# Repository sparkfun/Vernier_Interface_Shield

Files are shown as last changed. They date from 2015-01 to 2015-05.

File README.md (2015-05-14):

Vernier Interface Shield
========================

Vernier Interface Shield

[*Vernier Interface Shield (DEV-12858)*](https://www.sparkfun.com/products/12858)

This shield enables Arduino Uno footprint compatible boards to be connected to Vernier sensors. 

Repository Contents
-------------------

* **/Hardware** - Eagle PCB layout files
* **/Libraries** - Arduino library for using the Vernier Shield
* **/Production** - Files to support SparkFun production

Documentation
--------------
* **[Library](https://github.com/sparkfun/SparkFun_Vernier_Interface_Shield_Arduino_Library)** - Arduino library for the Vernier shield. 
* **[Hookup Guide](https://learn.sparkfun.com/tutorials/vernier-shield-hookup-guide)** - Basic hookup guide for the Vernier Shield.
* **[SparkFun Fritzing repo](https://github.com/sparkfun/Fritzing_Parts)** - Fritzing diagrams for SparkFun products.
* **[SparkFun 3D Model repo](https://github.com/sparkfun/3D_Models)** - 3D models of SparkFun products. 

Product Versions
----------------
* [DEV-11897](https://www.sparkfun.com/products/retired/11897)- Hardware version 1.1. Retired. 

Version History
---------------
* [v1.2](https://github.com/sparkfun/Vernier_Interface_Shield/tree/v1.2) -GitHub version 1.2
* [v1.1](https://github.com/sparkfun/Vernier_Interface_Shield/tree/v1.1) -GitHub version 1.1

License Information
-------------------
This product is _**open source**_! 

The **hardware** is released under [Creative Commons ShareAlike 4.0 International](https://creativecommons.org/licenses/by-sa/4.0/).

The **code** is beerware; if you see me (or any other SparkFun employee) at the local, and you've found our code helpful, please buy us a round!

Please use, reuse, and modify these files as you see fit. Please maintain attribution to SparkFun Electronics and release anything derivative under the same license.

Distributed as-is; no warranty is given.

- Your friends at SparkFun.

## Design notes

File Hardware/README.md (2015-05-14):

SparkFun <PRODUCT NAME> Design Files
=====================================

The .sch and .brd files hare are Eagle CAD schematic and PCB design files from SparkFun Electronics.
A freeware version of Eagle can be found [here](http://www.cadsoftusa.com/download-eagle/freeware/). 

License
---------
This product is open source! 
The hardware is released under [Creative Commons ShareAlike 4.0 International](https://creativecommons.org/licenses/by-sa/4.0/).

Please use, reuse, and modify these files as you see fit. Please maintain attribution to SparkFun Electronics and release anything derivative under the same license.

Distributed as-is; no warranty is given.

- Your friends at SparkFun.

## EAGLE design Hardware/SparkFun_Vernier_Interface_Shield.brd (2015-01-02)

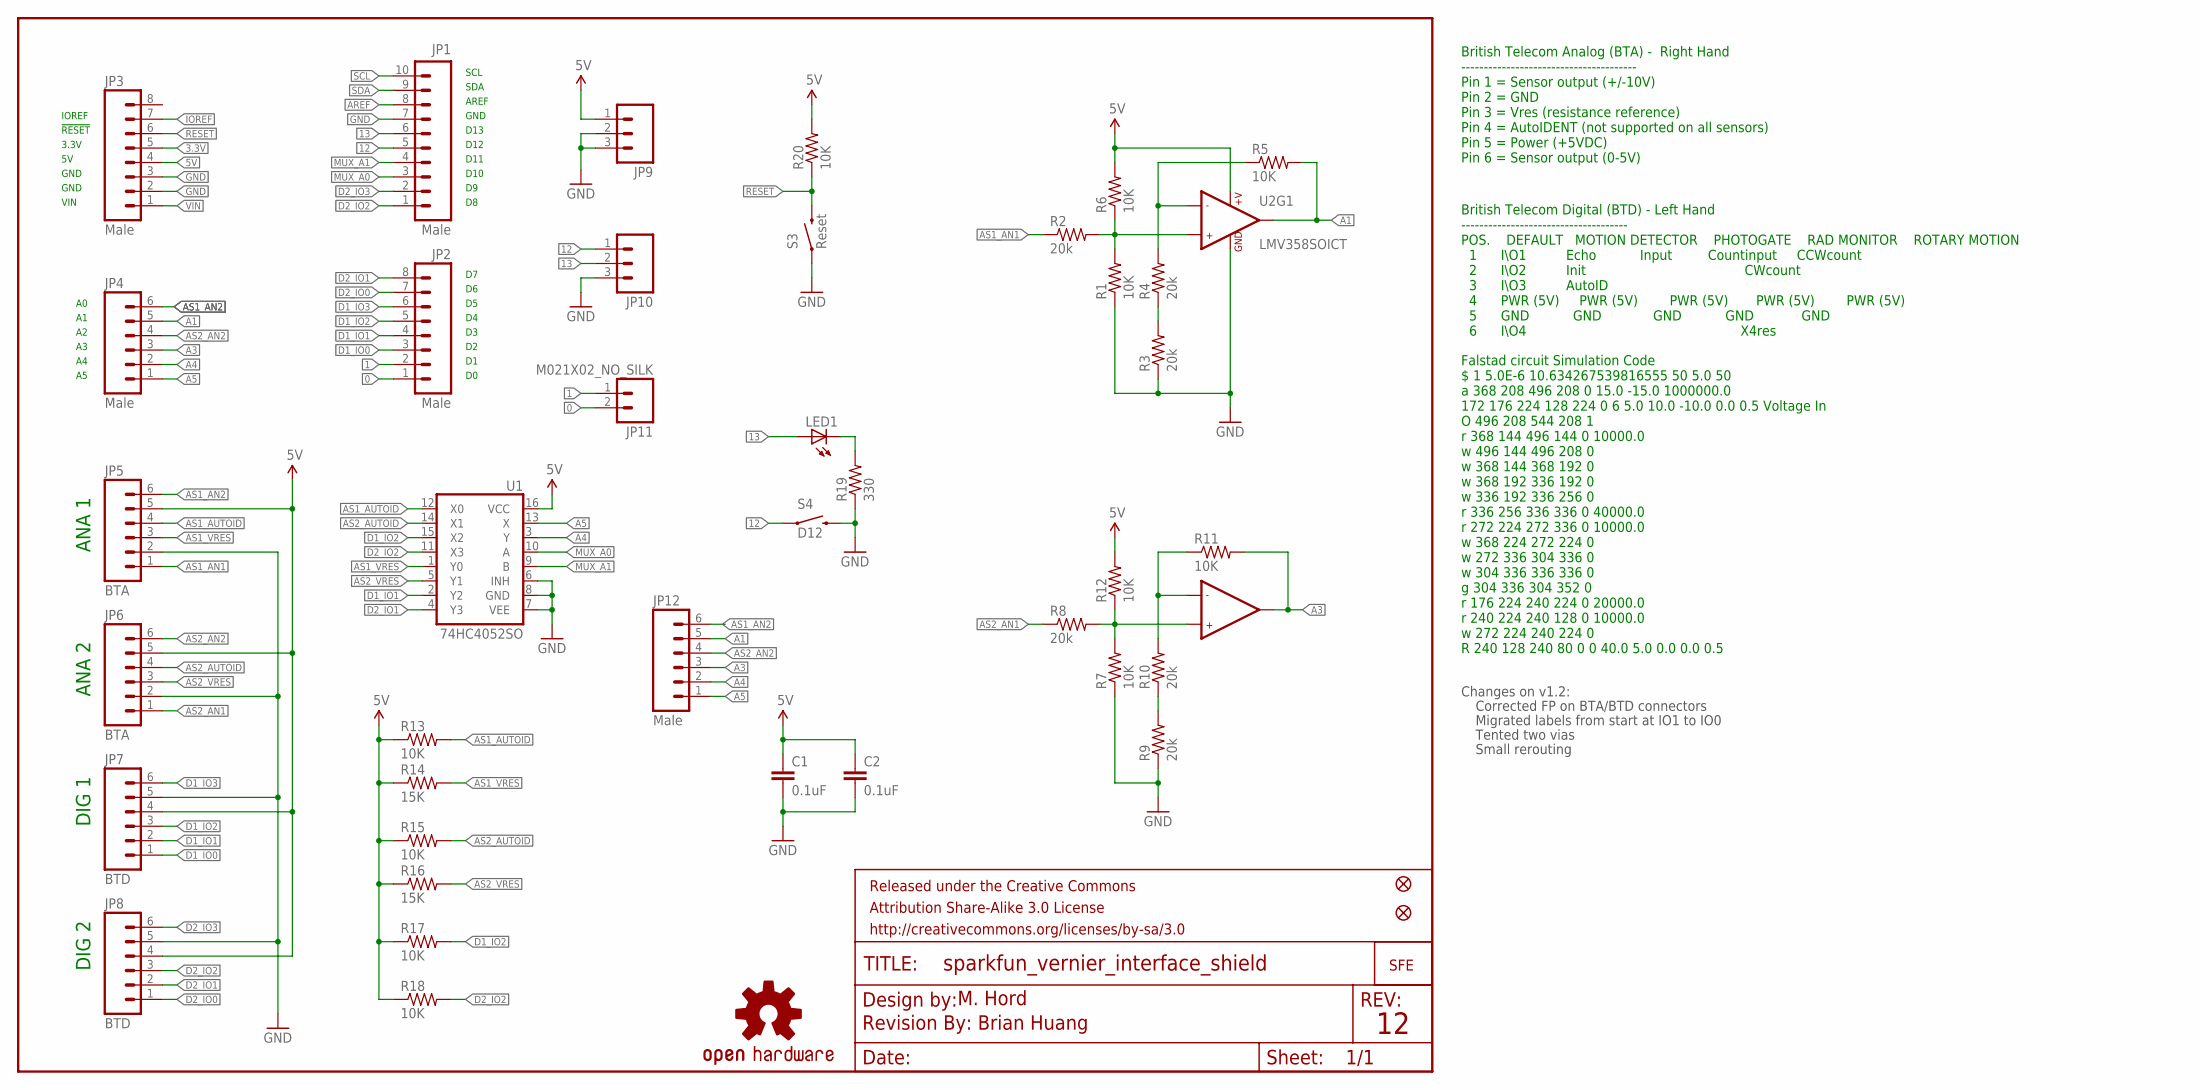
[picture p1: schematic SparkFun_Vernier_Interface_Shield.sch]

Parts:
C1, C2: 0.1uF; 0603-CAP
FID1, FID2: FIDUCIAL1X2; FIDUCIAL-1X2
FRAME1: FRAME-LETTER; CREATIVE_COMMONS
JP1: Male; 1X10_SMD_MALE
JP2, JP3: Male; 1X08_SMD_MALE
JP4: Male; 1X06_SMD_MALE
JP5, JP6: BTA
JP7, JP8: BTD
JP9, JP10: M031X03_NO_SILK; 1X03_NO_SILK
JP11: M021X02_NO_SILK; 1X02_NO_SILK
JP12: Male; 1X06
LED1: LED5MM
LOGO2: OSHW-LOGOS; OSHW-LOGO-S
LOGO_1: LOGO-SFESK; SFE-LOGO-FLAME
R1, R5, R6, R7, R11, R12, R13, R15, R17, R18, R20: 10K; 0603-RES
R2, R3, R4, R8, R9, R10: 20k; 0603-RES
R14, R16: 15K; 0603-RES
R19: 330; 0603-RES
S3: Reset; TACTILE-PTH
S4: D12; TACTILE-PTH
U1: 74HC4052SO; SO16
U2: LMV358SOICT; SO08-TIGHT
U$1: REVISION

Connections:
0: JP2.1, JP11.2
1: JP2.2, JP11.1
3.3V: JP3.5
5V: C1.1, C2.1, JP3.4, JP5.5, JP6.5, JP7.4, JP8.4, JP9.1, R6.2, R12.2, R13.1, R14.1, R15.1, R16.1, R17.1, R18.1, R20.2, U1.16 (VCC), U2.8 (+V)
12: JP1.5, JP10.1, S4.1
13: JP1.6, JP10.2, LED1.A
A1: JP4.5, JP12.5, R5.2, U2.1 (OUT1)
A3: JP4.3, JP12.3, R11.2, U2.7 (OUT2)
A4: JP4.2, JP12.2, U1.3 (Y)
A5: JP4.1, JP12.1, U1.13 (X)
AREF: JP1.8
AS1_AN1: JP5.1, R2.1
AS1_AN2: JP4.6, JP5.6, JP12.6
AS1_AUTOID: JP5.4, R13.2, U1.12 (X0)
AS1_VRES: JP5.3, R14.2, U1.1 (Y0)
AS2_AN1: JP6.1, R8.1
AS2_AN2: JP4.4, JP6.6, JP12.4
AS2_AUTOID: JP6.4, R15.2, U1.14 (X1)
AS2_VRES: JP6.3, R16.2, U1.5 (Y1)
D1_IO0: JP2.3, JP7.1
D1_IO1: JP2.4, JP7.2, U1.2 (Y2)
D1_IO2: JP2.5, JP7.3, R17.2, U1.15 (X2)
D1_IO3: JP2.6, JP7.6
D2_IO0: JP2.7, JP8.1
D2_IO1: JP2.8, JP8.2, U1.4 (Y3)
D2_IO2: JP1.1, JP8.3, R18.2, U1.11 (X3)
D2_IO3: JP1.2, JP8.6
GND: C1.2, C2.2, JP1.7, JP3.2, JP3.3, JP5.2, JP6.2, JP7.5, JP8.5, JP9.2, JP9.3, JP10.3, R1.1, R3.1, R7.1, R9.1, R19.1, S3.1, S4.3 (2), U1.6 (INH), U1.7 (VEE), U1.8 (GND), U2.4 (GND)
IOREF: JP3.7
MUX_A0: JP1.3, U1.10 (A)
MUX_A1: JP1.4, U1.9 (B)
unnamed: R1.2, R2.2, R6.1, U2.3 (+IN1)
unnamed: R3.2, R4.1
unnamed: R4.2, R5.1, U2.2 (-IN1)
unnamed: R9.2, R10.1
unnamed: R7.2, R8.2, R12.1, U2.5 (+IN2)
unnamed: R10.2, R11.1, U2.6 (-IN2)
unnamed: LED1.K (C), R19.2
RESET: JP3.6, R20.1, S3.3 (2)
SCL: JP1.10
SDA: JP1.9
VIN: JP3.1

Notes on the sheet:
SCL
SDA
AREF
GND
D13
D12
D11
D10
VIN
3.3V
!RESET
IOREF
ANA 1
ANA 2
DIG 1
DIG 2
M. Hord
British Telecom Analog (BTA) - Right Hand --------------------------------------- Pin 1 = Sensor output (+/-10V) Pin 2 = GND Pin 3 = Vres (resistance reference) Pin 4 = AutoIDENT (not supported on all sensors) Pin 5 = Power (+5VDC) Pin 6 = Sensor output (0-5V)
British Telecom Digital (BTD) - Left Hand ------------------------------------- POS. DEFAULT MOTION DETECTOR PHOTOGATE RAD MONITOR ROTARY MOTION 1 I\\O1 Echo Input Countinput CCWcount 2 I\\O2 Init CWcount 3 I\\O3 AutoID 4 PWR (5V) PWR (5V) PWR (5V) PWR (5V) PWR (5V) 5 GND GND GND GND GND 6 I\\O4 X4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
Falstad circuit Simulation Code $ 1 5.0E-6 10.634267539816555 50 5.0 50 a 368 208 496 208 0 15.0 -15.0 1000000.0 172 176 224 128 224 0 6 5.0 10.0 -10.0 0.0 0.5 Voltage In O 496 208 544 208 1 r 368 144 496 144 0 10000.0 w 496 144 496 208 0 w 368 144 368 192 0 w 368 192 336 192 0 w 336 192 336 256 0 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
Changes on v1.2:
Corrected FP on BTA/BTD connectors
Migrated labels from start at IO1 to IO0
Tented two vias
Small rerouting
Brian Huang

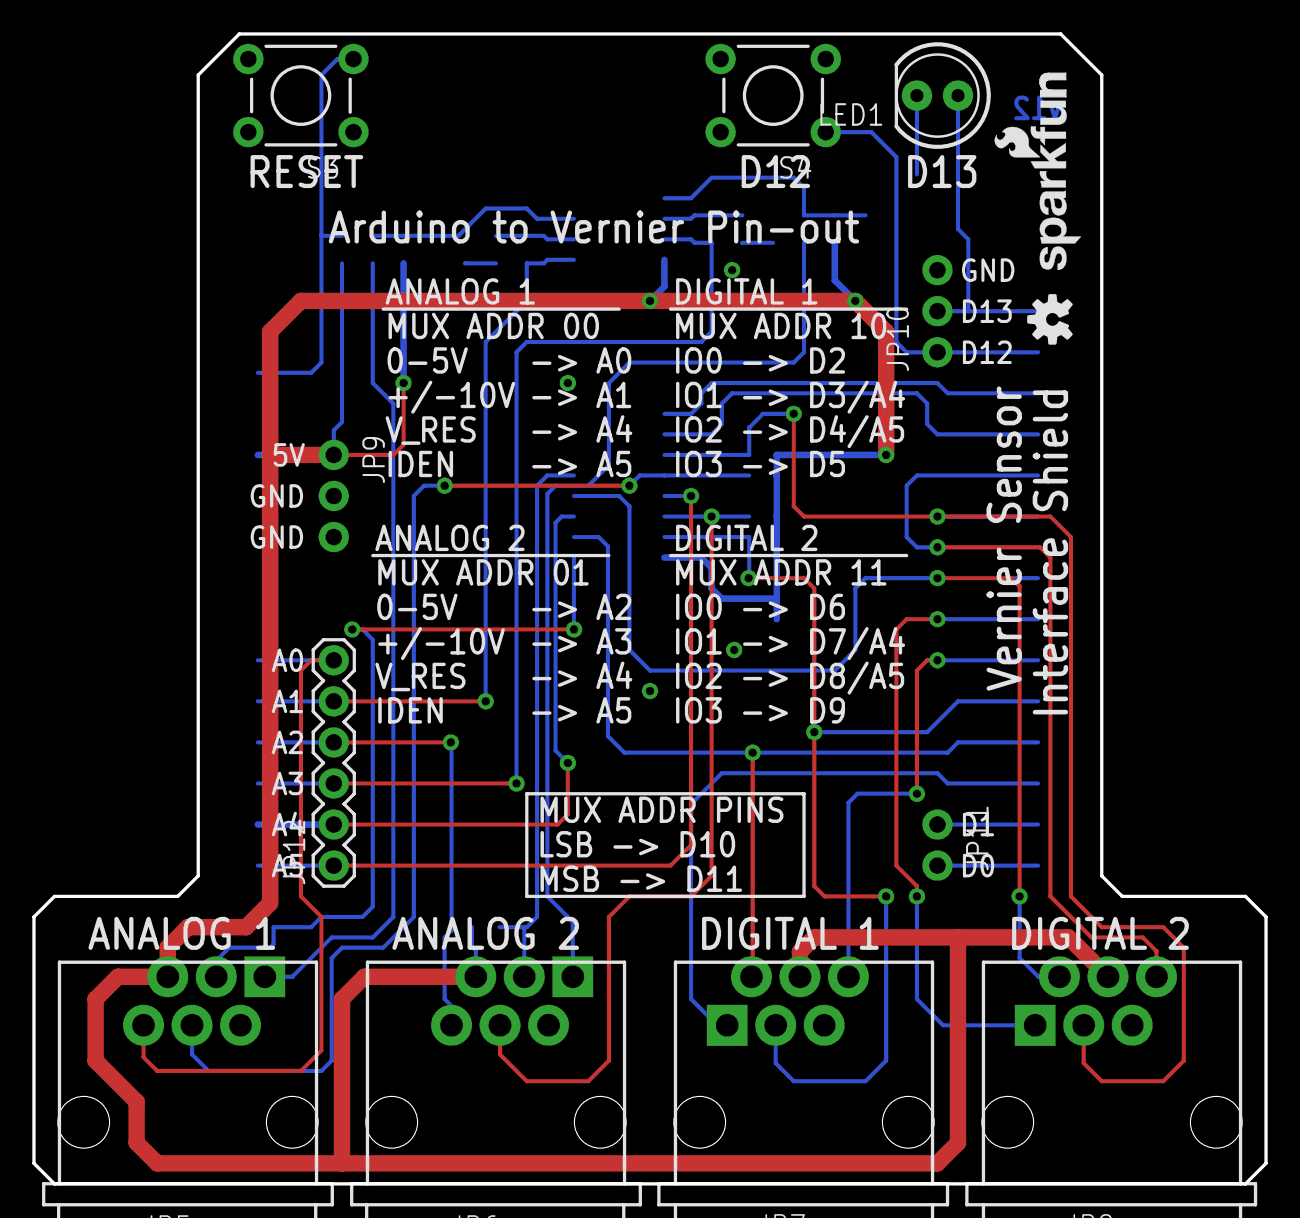
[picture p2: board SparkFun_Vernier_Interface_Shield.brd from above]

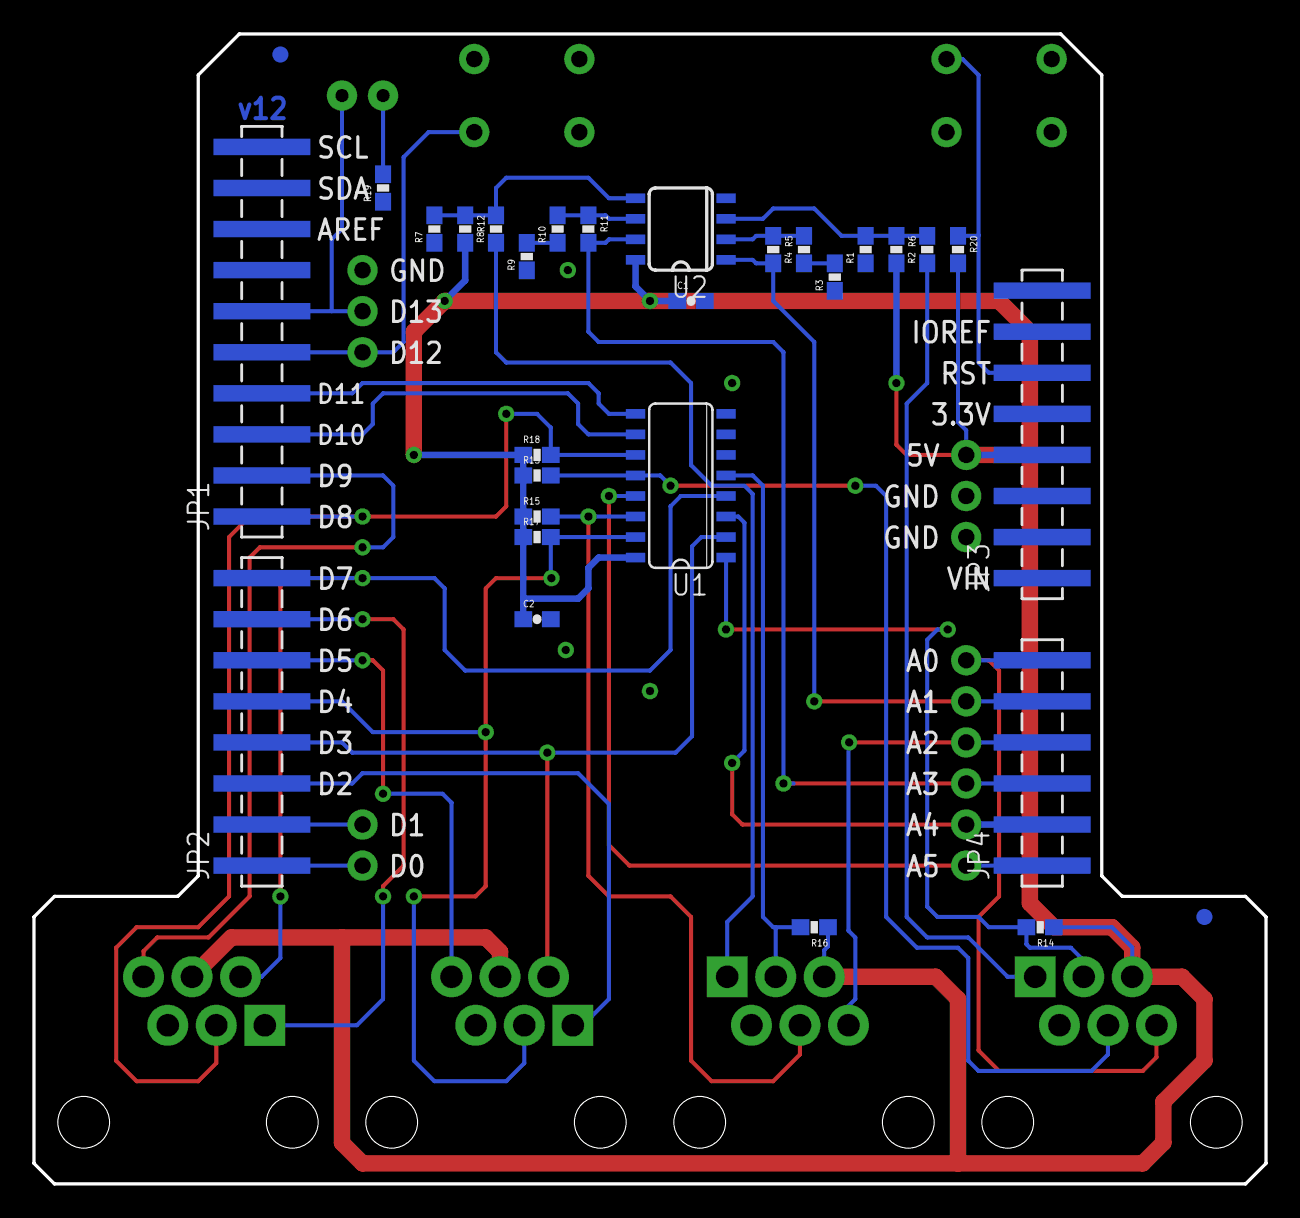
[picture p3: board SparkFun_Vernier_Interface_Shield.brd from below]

Board: 2 copper layers, 76.2 x 71.1 mm, 46 parts (30 on the bottom side), 36 nets.

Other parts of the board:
LOGO_3: LOGO-SFENW2; SFE-NEW-WEB

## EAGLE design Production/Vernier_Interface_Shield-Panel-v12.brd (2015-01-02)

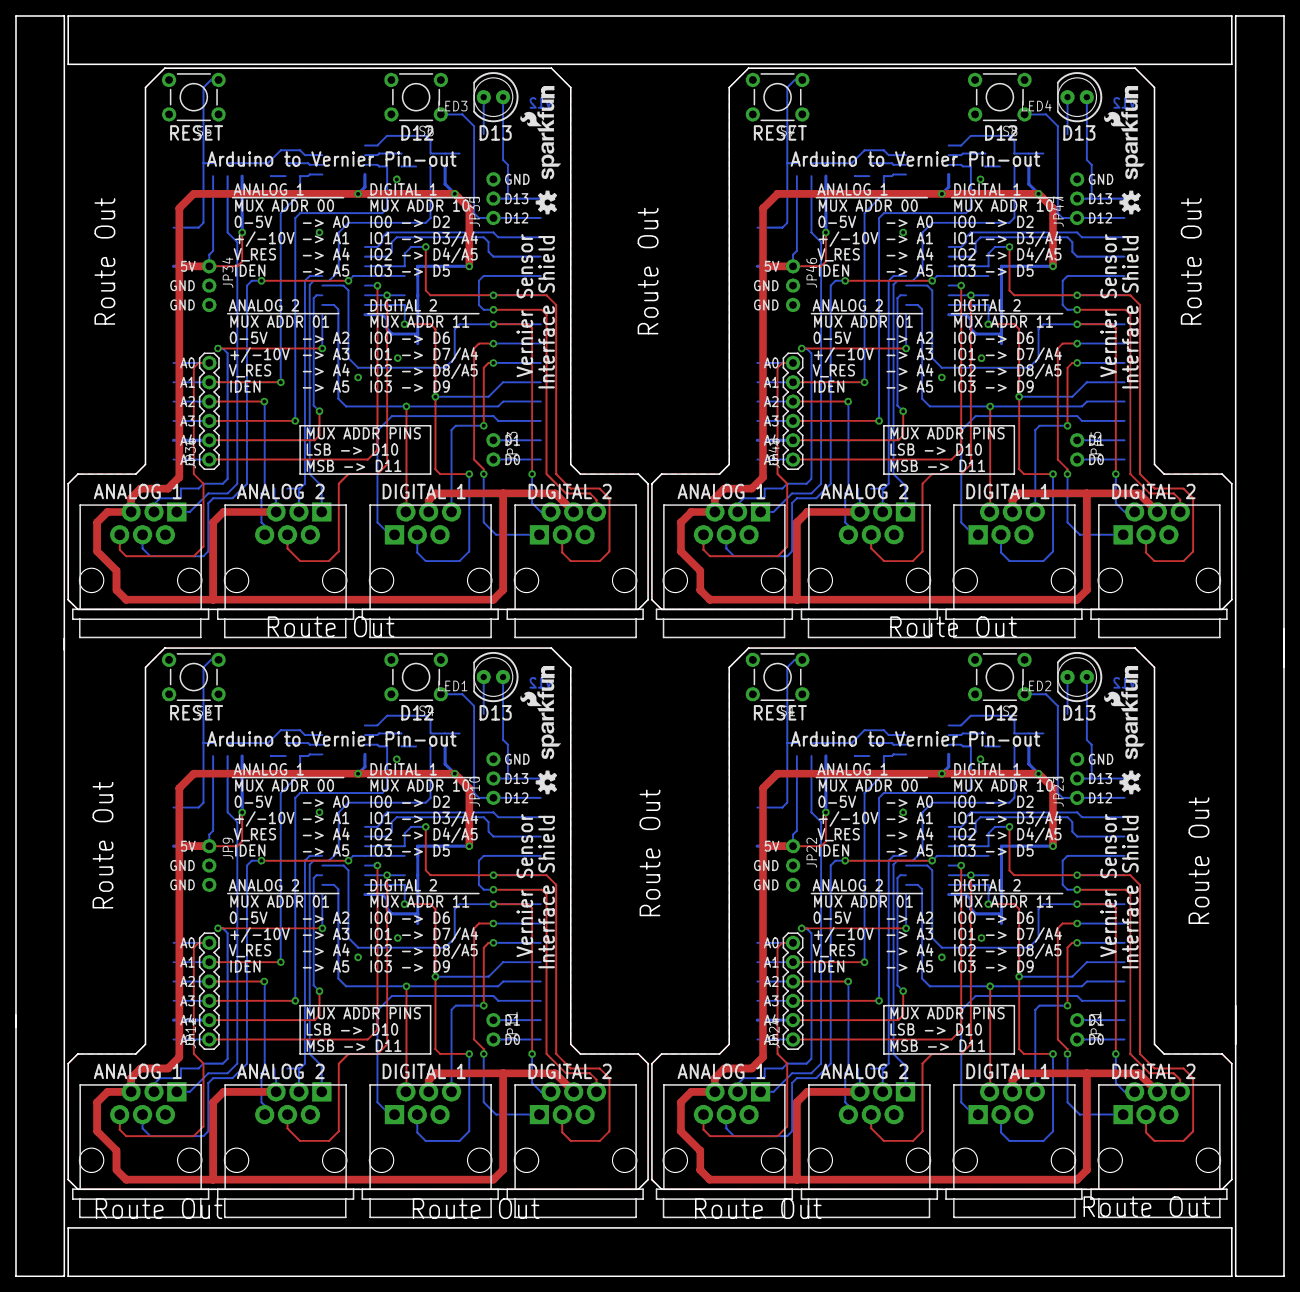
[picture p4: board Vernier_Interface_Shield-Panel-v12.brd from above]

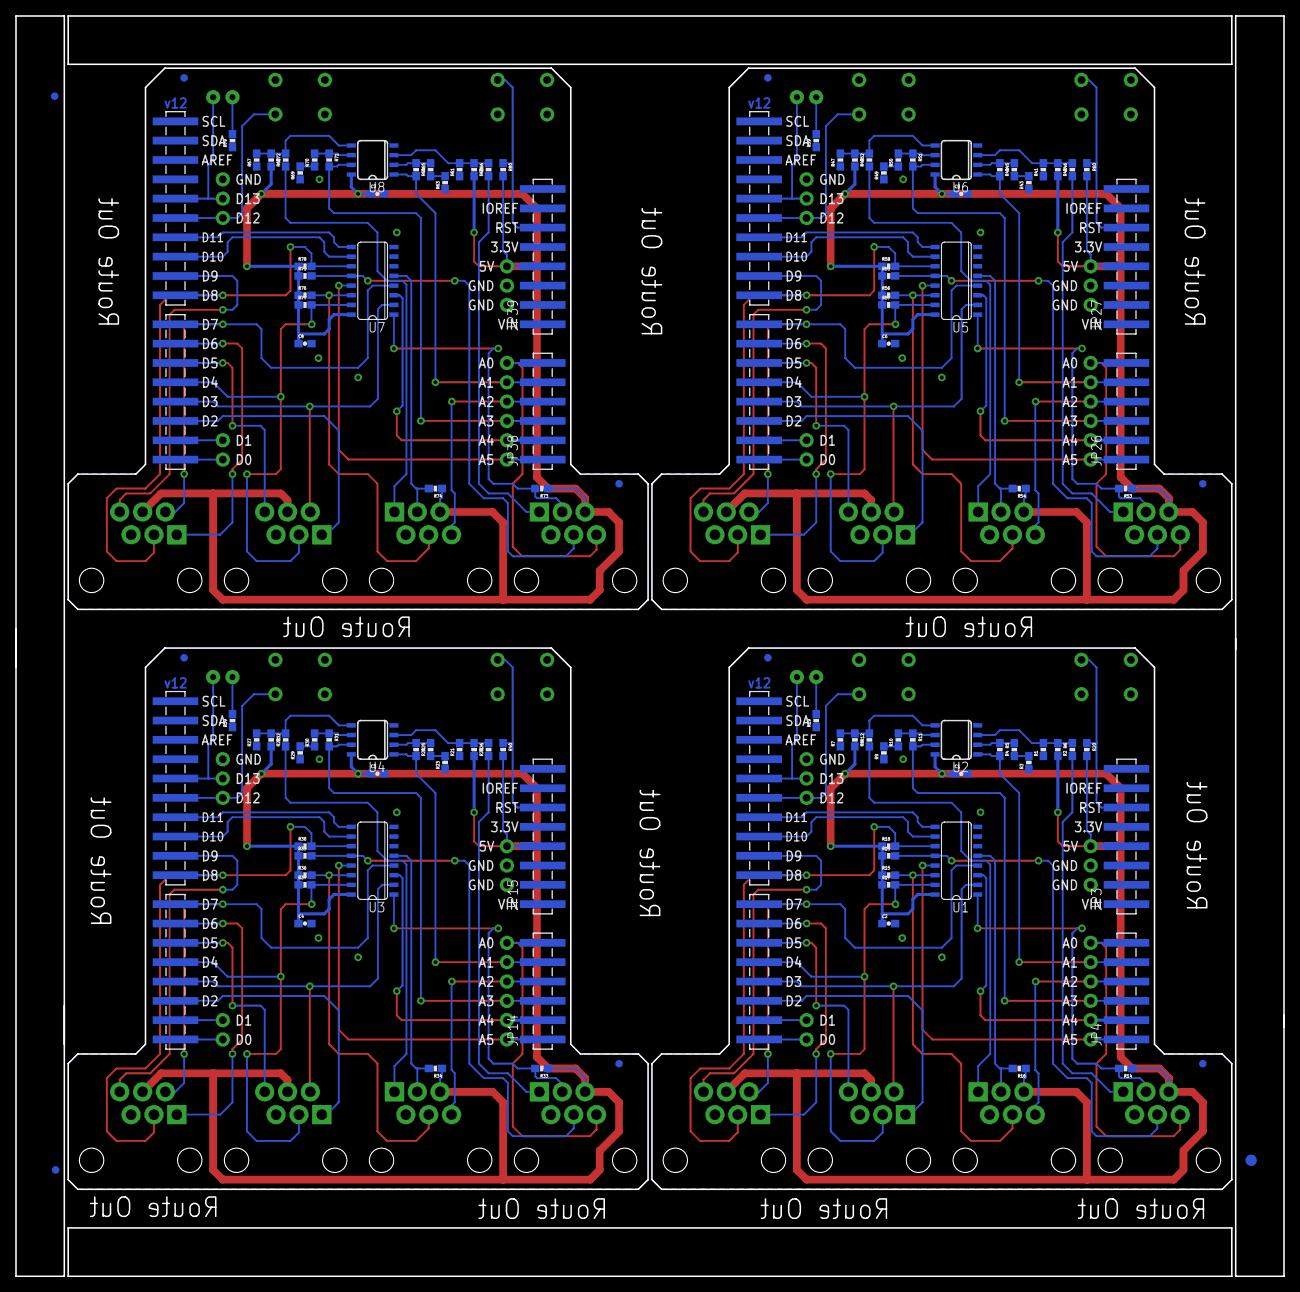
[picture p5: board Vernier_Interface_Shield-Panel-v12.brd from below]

Board: 2 copper layers, 166.6 x 165.6 mm, 179 parts (123 on the bottom side), 144 nets.

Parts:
C1, C2, C3, C4, C5, C6, C7, C8: 0.1uF; 0603-CAP
E$1: FIDUCIAL-1.5X3
E$4, E$6: FIDUCIAL-1X2
FID1, FID2, FID3, FID4, FID5, FID6, FID7, FID8: FIDUCIAL1X2; FIDUCIAL-1X2
JP1, JP13, JP25, JP37: Male; 1X10_SMD_MALE
JP2, JP3, JP15, JP16, JP27, JP28, JP39, JP40: Male; 1X08_SMD_MALE
JP4, JP14, JP26, JP38: Male; 1X06_SMD_MALE
JP5, JP6, JP18, JP19, JP30, JP31, JP42, JP43: BTA
JP7, JP8, JP17, JP20, JP29, JP32, JP41, JP44: BTD
JP9, JP10, JP22, JP23, JP34, JP35, JP46, JP47: 1X03_NO_SILK
JP11, JP21, JP33, JP45: M021X02_NO_SILK; 1X02_NO_SILK
JP12, JP24, JP36, JP48: Male; 1X06
LED1, LED2, LED3, LED4: LED5MM
LOGO1, LOGO2, LOGO3, LOGO4: OSHW-LOGOS; OSHW-LOGO-S
LOGO_1, LOGO_4, LOGO_6, LOGO_8: LOGO-SFESK; SFE-LOGO-FLAME
LOGO_2, LOGO_3, LOGO_5, LOGO_7: LOGO-SFENW2; SFE-NEW-WEB
R1, R5, R6, R7, R11, R12, R13, R15, R17, R18, R20, R21, R25, R26, R27, R31, R32, R35, R36, R37, R38, R40, R41, R45, R46, R47, R51, R52, R55, R56, R57, R58, R60, R61, R65, R66, R67, R71, R72, R75, R76, R77, R78, R80: 10K; 0603-RES
R2, R3, R4, R8, R9, R10, R22, R23, R24, R28, R29, R30, R42, R43, R44, R48, R49, R50, R62, R63, R64, R68, R69, R70: 20k; 0603-RES
R14, R16, R33, R34, R53, R54, R73, R74: 15K; 0603-RES
R19, R39, R59, R79: 330; 0603-RES
S1, S3, S5, S7: Reset; TACTILE-PTH
S2, S4, S6, S8: D12; TACTILE-PTH
U1, U3, U5, U7: 74HC4052SO; SO16
U2, U4, U6, U8: LMV358SOICT; SO08-TIGHT

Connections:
0: JP2.1, JP11.2
1: JP2.2, JP11.1
2: JP13.5, JP23.1, S2.1
3: JP16.1, JP21.2
4: JP16.2, JP21.1
5: JP13.6, JP23.2, LED2.A
5V: C1.1, C2.1, JP3.4, JP5.5, JP6.5, JP7.4, JP8.4, JP9.1, R6.2, R12.2, R13.1, R14.1, R15.1, R16.1, R17.1, R18.1, R20.2, U1.16, U2.8
5V1: C3.1, C4.1, JP15.4, JP17.4, JP18.5, JP19.5, JP20.4, JP22.1, R26.2, R32.2, R33.1, R34.1, R35.1, R36.1, R37.1, R38.1, R40.2, U3.16, U4.8
5V2: C5.1, C6.1, JP27.4, JP29.4, JP30.5, JP31.5, JP32.4, JP34.1, R46.2, R52.2, R53.1, R54.1, R55.1, R56.1, R57.1, R58.1, R60.2, U5.16, U6.8
5V3: C7.1, C8.1, JP39.4, JP41.4, JP42.5, JP43.5, JP44.4, JP46.1, R66.2, R72.2, R73.1, R74.1, R75.1, R76.1, R77.1, R78.1, R80.2, U7.16, U8.8
6: JP25.5, JP35.1, S6.1
7: JP28.1, JP33.2
8: JP28.2, JP33.1
9: JP25.6, JP35.2, LED3.A
10: JP37.5, JP47.1, S8.1
11: JP40.1, JP45.2
12: JP1.5, JP10.1, S4.1
13: JP1.6, JP10.2, LED1.A
14: JP40.2, JP45.1
15: JP37.6, JP47.2, LED4.A
A1: JP4.5, JP12.5, R5.2, U2.1
A2: JP14.2, JP24.2, U3.3
A3: JP4.3, JP12.3, R11.2, U2.7
A4: JP4.2, JP12.2, U1.3
A5: JP4.1, JP12.1, U1.13
A6: JP14.1, JP24.1, U3.13
A7: JP14.5, JP24.5, R25.2, U4.1
A8: JP14.3, JP24.3, R31.2, U4.7
A9: JP26.2, JP36.2, U5.3
A10: JP26.1, JP36.1, U5.13
A11: JP26.5, JP36.5, R45.2, U6.1
A12: JP26.3, JP36.3, R51.2, U6.7
A13: JP38.2, JP48.2, U7.3
A14: JP38.1, JP48.1, U7.13
A15: JP38.5, JP48.5, R65.2, U8.1
A16: JP38.3, JP48.3, R71.2, U8.7
AS1_AN1: JP5.1, R2.1
AS1_AN2: JP4.6, JP5.6, JP12.6
AS1_AN3: JP18.1, R22.1
AS1_AN4: JP14.6, JP18.6, JP24.6
AS1_AN5: JP30.1, R42.1
AS1_AN6: JP26.6, JP30.6, JP36.6
AS1_AN7: JP42.1, R62.1
AS1_AN8: JP38.6, JP42.6, JP48.6
AS1_AUTOID: JP5.4, R13.2, U1.12
AS1_AUTOID1: JP18.4, R35.2, U3.12
AS1_AUTOID2: JP30.4, R55.2, U5.12
AS1_AUTOID3: JP42.4, R75.2, U7.12
AS1_VRES: JP5.3, R14.2, U1.1
AS1_VRES1: JP18.3, R33.2, U3.1
AS1_VRES2: JP30.3, R53.2, U5.1
AS1_VRES3: JP42.3, R73.2, U7.1
AS2_AN1: JP6.1, R8.1
AS2_AN2: JP4.4, JP6.6, JP12.4
AS2_AN3: JP14.4, JP19.6, JP24.4
AS2_AN4: JP19.1, R28.1
AS2_AN5: JP26.4, JP31.6, JP36.4
AS2_AN6: JP31.1, R48.1
AS2_AN7: JP38.4, JP43.6, JP48.4
AS2_AN8: JP43.1, R68.1
AS2_AUTOID: JP6.4, R15.2, U1.14
AS2_AUTOID1: JP19.4, R36.2, U3.14
AS2_AUTOID2: JP31.4, R56.2, U5.14
AS2_AUTOID3: JP43.4, R76.2, U7.14
AS2_VRES: JP6.3, R16.2, U1.5
AS2_VRES1: JP19.3, R34.2, U3.5
AS2_VRES2: JP31.3, R54.2, U5.5
AS2_VRES3: JP43.3, R74.2, U7.5
D1_IO0: JP2.3, JP7.1
D1_IO1: JP2.4, JP7.2, U1.2
D1_IO2: JP2.5, JP7.3, R17.2, U1.15
D1_IO3: JP2.6, JP7.6
D1_IO4: JP16.6, JP17.6
D1_IO5: JP16.5, JP17.3, R37.2, U3.15
D1_IO6: JP16.4, JP17.2, U3.2
D1_IO7: JP16.3, JP17.1
D1_IO8: JP28.6, JP29.6
D1_IO9: JP28.5, JP29.3, R57.2, U5.15
D1_IO10: JP28.4, JP29.2, U5.2
D1_IO11: JP28.3, JP29.1
D1_IO12: JP40.6, JP41.6
D1_IO13: JP40.5, JP41.3, R77.2, U7.15
D1_IO14: JP40.4, JP41.2, U7.2
D1_IO15: JP40.3, JP41.1
D2_IO0: JP2.7, JP8.1
D2_IO1: JP2.8, JP8.2, U1.4
D2_IO2: JP1.1, JP8.3, R18.2, U1.11
D2_IO3: JP1.2, JP8.6
D2_IO4: JP13.2, JP20.6
D2_IO5: JP13.1, JP20.3, R38.2, U3.11
D2_IO6: JP16.8, JP20.2, U3.4
D2_IO7: JP16.7, JP20.1
D2_IO8: JP25.2, JP32.6
D2_IO9: JP25.1, JP32.3, R58.2, U5.11
D2_IO10: JP28.8, JP32.2, U5.4
D2_IO11: JP28.7, JP32.1
D2_IO12: JP37.2, JP44.6
D2_IO13: JP37.1, JP44.3, R78.2, U7.11
D2_IO14: JP40.8, JP44.2, U7.4
D2_IO15: JP40.7, JP44.1
GND: C1.2, C2.2, JP1.7, JP3.2, JP3.3, JP5.2, JP6.2, JP7.5, JP8.5, JP9.2, JP9.3, JP10.3, R1.1, R3.1, R7.1, R9.1, R19.1, S3.1, S4.3, U1.6, U1.7, U1.8, U2.4
GND1: C3.2, C4.2, JP13.7, JP15.2, JP15.3, JP17.5, JP18.2, JP19.2, JP20.5, JP22.2, JP22.3, JP23.3, R21.1, R23.1, R27.1, R29.1, R39.1, S1.1, S2.3, U3.6, U3.7, U3.8, U4.4
GND2: C5.2, C6.2, JP25.7, JP27.2, JP27.3, JP29.5, JP30.2, JP31.2, JP32.5, JP34.2, JP34.3, JP35.3, R41.1, R43.1, R47.1, R49.1, R59.1, S5.1, S6.3, U5.6, U5.7, U5.8, U6.4
GND3: C7.2, C8.2, JP37.7, JP39.2, JP39.3, JP41.5, JP42.2, JP43.2, JP44.5, JP46.2, JP46.3, JP47.3, R61.1, R63.1, R67.1, R69.1, R79.1, S7.1, S8.3, U7.6, U7.7, U7.8, U8.4
MUX_A0: JP1.3, U1.10
MUX_A1: JP1.4, U1.9
MUX_A2: JP13.3, U3.10
MUX_A3: JP13.4, U3.9
MUX_A4: JP25.3, U5.10
MUX_A5: JP25.4, U5.9
MUX_A6: JP37.3, U7.10
MUX_A7: JP37.4, U7.9
unnamed: R1.2, R2.2, R6.1, U2.3
unnamed: R3.2, R4.1
unnamed: R4.2, R5.1, U2.2
unnamed: R23.2, R24.1
unnamed: R9.2, R10.1
unnamed: R7.2, R8.2, R12.1, U2.5
unnamed: R10.2, R11.1, U2.6
unnamed: LED1.K, R19.2
unnamed: R21.2, R22.2, R26.1, U4.3
unnamed: R24.2, R25.1, U4.2
unnamed: R29.2, R30.1
unnamed: R27.2, R28.2, R32.1, U4.5
unnamed: R30.2, R31.1, U4.6
unnamed: LED2.K, R39.2
unnamed: R43.2, R44.1
unnamed: R41.2, R42.2, R46.1, U6.3
unnamed: R44.2, R45.1, U6.2
unnamed: R49.2, R50.1
unnamed: R47.2, R48.2, R52.1, U6.5
unnamed: R50.2, R51.1, U6.6
unnamed: LED3.K, R59.2
unnamed: R63.2, R64.1
unnamed: R61.2, R62.2, R66.1, U8.3
unnamed: R64.2, R65.1, U8.2
unnamed: R69.2, R70.1
unnamed: R67.2, R68.2, R72.1, U8.5
unnamed: R70.2, R71.1, U8.6
unnamed: LED4.K, R79.2
RESET: JP3.6, R20.1, S3.3
RESET1: JP15.6, R40.1, S1.3
RESET2: JP27.6, R60.1, S5.3
RESET3: JP39.6, R80.1, S7.3

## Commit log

2013-06-10 Ready for protos
    [Vernier_Interface_Shield.brd, Vernier_Interface_Shield.sch]
2013-08-15 Tweaks towards v02
    [Vernier_Interface_Shield.brd, Vernier_Interface_Shield.sch]
2013-08-22 Updated footprints of BTA and BTD
    Fixed the footprints of BTA and BTD.
    Corrected the BTD pin numbering.
    Rotated the design so that the connectors don't short out on the USB
    cage.
    V03
    [Vernier_Interface_Shield.brd, Vernier_Interface_Shield.sch]
2013-08-23 Fixed traces, ran DRC, etc...
    Updated traces, fixed errors in DRC... more tweaks toward v02
    [Vernier_Interface_Shield.brd, Vernier_Interface_Shield.sch]
2013-08-26 addtl clean-up: corrected resistor spacing
    Corrected resistor spacing and cleaned-up resulting traces.
    [Vernier_Interface_Shield.brd, Vernier_Interface_Shield.sch]
2013-08-27 Updated footprints of BTA and BTD connectors
    [Vernier_Interface_Shield.brd, Vernier_Interface_Shield.sch]
2013-08-27 Ready for protos!
    Everything's ready to go! No changes to the BOM. Can we order 4 protos
    this time?
    [Vernier_Interface_Shield.sch]
2013-08-28 One last update for v02 - updated bottom silk
    Updated bottom silk for where VIAS are interfering with the pin labels.
    [Vernier_Interface_Shield.brd]
2013-09-21 Changed Pins 2 and 3 to BTD connector 1
    Changed circuit so that Pins 2 and 3 are connected to BTD 1 - allows for
    use of Hardware interrupts from Arduino.
    Also cleaned up silks
    [Vernier_Interface_Shield.brd, Vernier_Interface_Shield.sch]
2013-09-23 Changed pins one last time...
    Changed Digital Pins so that it's pins 2, 3, 4, 5 on Dig 1 and 6, 7, 8
    ,9 on Dig 2
    [Vernier_Interface_Shield.brd, Vernier_Interface_Shield.sch]
2013-09-23 Updated revision code - ready for protos
    Hopefully the last round of protos for this board. - Updated silks,
    moved VIAS so as not to interfere with printing.
    [Vernier_Interface_Shield.brd]
2013-10-22 Switched Digital 1 and Digital 2 on the Board
    Fixed the Digital 1 and Digital 2. V03 had the two connectors flipped.
    [Vernier_Interface_Shield.brd, Vernier_Interface_Shield.sch]
2013-10-28 Adjusted silk on digital header list
    [Vernier_Interface_Shield.brd]
2013-10-31 Initial start of Vernier Library routines
    [testing_data_10V_input.xlsx]
2013-11-14 Release version
    [Vernier_Interface_Shield.brd, Vernier_Interface_Shield.sch]
2013-11-14 Added micro Fiducial to board
    [Vernier_Interface_Shield.brd, Vernier_Interface_Shield.sch]
2013-11-14 Created Panel
    [Vernier_Interface_Shield-Panel-v10.brd]
2013-11-14 Added "Route Out" for GP routing
    [Vernier_Interface_Shield-Panel-v10.brd]
2013-12-09 Put on grid, rm weird stop on back, to v11
    [Vernier_Interface_Shield.brd, Vernier_Interface_Shield.sch]
2013-12-09 Move borders to 50th grid lines
    [Vernier_Interface_Shield.brd]
2013-12-09 Re-created Panel v11
    [Vernier_Interface_Shield-Panel-v10.brd, Vernier_Interface_Shield-Panel-v11.brd, Vernier_Interface_Shield.brd]
2013-12-09 added route out for GP
    [Vernier_Interface_Shield-Panel-v11.brd]
2013-12-12 Move board outline from tDocu to Dimension
    [Vernier_Interface_Shield.brd]
2013-12-13 Re-re-created Panel v11
    [Vernier_Interface_Shield-Panel-v11.brd]
2014-01-18 Updated connector FPs. Tented some vias. Removed extra silk.
    The A5 to A0 labels were of different size and didn't see to go
    anywhere. Removed them.
    [Vernier_Interface_Shield.brd, Vernier_Interface_Shield.sch]
2014-01-18 Shrunk board. Updated version number to 1.2.
    [Vernier_Interface_Shield.brd]
2014-01-18 Touched up schematic. Updated version number.
    Pushed some schematic components onto grid. Replaced button symbols with
    single action symbol.
    [Vernier_Interface_Shield.brd, Vernier_Interface_Shield.sch]
2014-01-18 Small component/silk overlap fix.
    [Vernier_Interface_Shield.brd]
2014-01-30 Repo clean up and README update
    [testing_data_10V_input.xlsx]
2014-02-06 Changed silk to fix bug #4
    Changed silk to start at IO0 instead of IO1. This is per Vernier's
    request.
    [Vernier_Interface_Shield.brd, Vernier_Interface_Shield.sch]
2014-04-21 Updated A0-A5 vias to be exposed to allow for probe pins
    Swapped out 6 vias on A0 to A5 with M06 for exposed copper vias to allow
    for probe points
    [Vernier_Interface_Shield.brd, Vernier_Interface_Shield.sch]
2014-07-23 Updated the Top layer Silk
    Updated top layer silk to have A0-A5 next to the exposed vias. Moved the
    exposed vias for 5V and GND to line up with A0-A5.
    [Vernier_Interface_Shield2.brd, Vernier_Interface_Shield2.sch]
2014-07-23 Deleted extra files
    Removed the extra vernier_interface_shield2.xxx files
    [Vernier_Interface_Shield2.brd, Vernier_Interface_Shield2.sch]
2014-07-23 Silk update
    Found two text labels A4 / A5 that weren't lined up. Fixed.
    [Vernier_Interface_Shield.brd]
2014-08-04 Fixing layout of license and adding revision by info
    [Vernier_Interface_Shield.brd, Vernier_Interface_Shield.sch]
2014-08-08 removed micro fids, added regular
    [Vernier_Interface_Shield.brd, Vernier_Interface_Shield.sch]
2014-08-08 created panel v12
    [Vernier_Interface_Shield-Panel-v12.brd]
2014-09-03 re-created panel v12 with proper spacing
    [Vernier_Interface_Shield-Panel-v11.brd, Vernier_Interface_Shield-Panel-v12.brd]
2015-04-24 Squashed 'Libraries/Arduino/' content from commit 605cf21
    git-subtree-dir: Libraries/Arduino
    git-subtree-split: 605cf21e6fa902c52472fac919dcde89b24b8e8a
2015-04-24 Changed library to new subtree.
    [Vernier_Interface_Shield-Panel-v12.brd]
2015-05-14 Updating README, fixing naming conventions
    [SparkFun_Vernier_Interface_Shield.brd, SparkFun_Vernier_Interface_Shield.sch]
2015-05-14 Squashed 'Libraries/Arduino/' changes from 605cf21..4488417
    git-subtree-split: 44884171363cd44c3c6dfda6376193d3172a4ff1
    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

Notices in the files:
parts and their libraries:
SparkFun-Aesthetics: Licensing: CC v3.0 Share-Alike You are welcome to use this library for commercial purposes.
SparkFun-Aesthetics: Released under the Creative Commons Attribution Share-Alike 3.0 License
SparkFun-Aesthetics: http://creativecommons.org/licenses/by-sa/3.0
